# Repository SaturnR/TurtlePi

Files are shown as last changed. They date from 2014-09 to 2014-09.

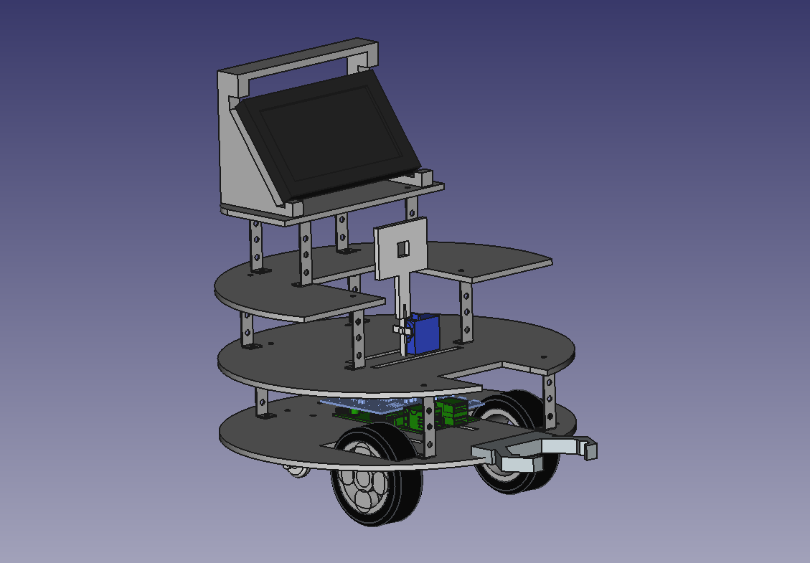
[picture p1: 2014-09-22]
Design/Screenshot from 2014-05-14 19:03:23.png

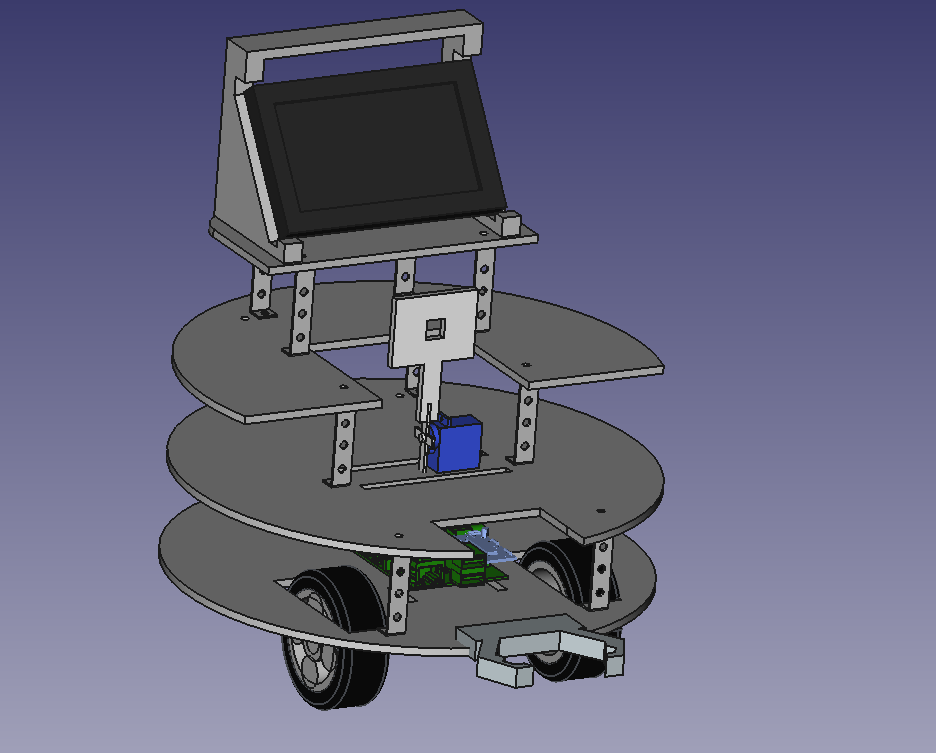
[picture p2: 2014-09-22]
Design/Screenshot from 2014-05-14 19:05:55.png

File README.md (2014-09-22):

TurtlePi
========

Programming and Electronics Learning Robotics kit, for students. 
 
TurtlePi is designed as a learning and research­experimenting robotics kit. 
It can be used for students from 12 year old to universities and colleges. 
kit is entirely modular, wide variety of sensors can be connected easily as a modules and 
actuators presented as a modules too. Robot contains two main board one is arduino 
compatible control board and another is raspberry pi computer, arduino control board is 
designed as shield for Raspberry Pi.  

Arduino board can be used as standalone control board, without Raspberry Pi computer and can 
perform low level tasks such as path planning, obstacle avoidance, line following, remote control. 
In addition with Raspberry Pi computer, robot gets much more complex functionality such as: 
object/face recognition, speech synthesis, Speech Recognition, dynamic programming and etc. 

robotics kit can be controlled and programmed wirelessly, 
In final design, robotics kit can be programmed with wide variety programming languages 
(python, javascript, c, c++, perl, c#) and visual languages like Google Blockly and Scratch.

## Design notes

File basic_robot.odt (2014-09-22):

1. რობოტი გათვლილია ფართო ასაკობრივი ჯგუფებისთვის, დაწყებული III კლასის მოსწავლეებიდან სტუდენტებით დამთავრებული.
2. პროექტი შესრულებულია მთლიანათ მოდულური პრინციპით, მოდულების სახით არის წარმოდგენილი როგორც მართვის ელემენტები ასევე გადამწოდები და შემსრულებელი მექანიზმები.
3. რობოტი წაროდგენილი იქნება ორი სახით, სრული და საბაზისო კომპლექტაციით.
4. სრული კომპლექტაციით შეიცავს ორ მათვის მოდულს, პირველი ეს არის Raspberry pi კომპიუტერი, ხოლო მეორე Arduino, რომელიც თავის მხრივ წარმოადგენს შილდს Raspberry pi-სთვის.
  სრული კომპლექტაციის პირობებში Raspberry pi წარმოადგენს რობოტის მმართველ მოდულს (ბრძანებების მიღება, ვიდეო გამოსახულების დამუშავება, …. ) , ხოლო არდუინო შილდს მხოლოდ პერიფერიული ამოცანების შესრულება აკისრია, როგორიცაა: სერვო ძრავების მართვა , გადამწოდებიდან ციფრული თუ ანალოგური სახის ინფორმაციის მიღება.
5. საბაზისო კომპლექტაციით, რობოტის მართვის მოდულს წარმოადგენს მხოლოდ Arduino მოდული. ხოლო Raspberry pi, RPi კამერა მოდული და მონიტორი არ შედის კომპლექტაციაში. ყველა დანარჩენი გადამწოდები და შემსრულებელი მექანიზმები გათვალისწინებულია კომპლექტაციაში.
6. რობოტის პროგრამირების პროცესი ასევე მნიშვენელოვნათ გამარტივებულია, ნებისმიერი კომპლექტაციის პირობებში პროგრამირების პროცესი არის დისტანციური და არ საჭიროებს სადენის ფიზიკურათ შეერთებას.
7. რობოტის პროგრამირების გარემო მრავალფეროვანია. რობოტის პროგრამირება შესაძლებელია რამოდენიმე პოპულარული პროგრამირების ენით (c, c++, java, perl, javascript, python, c#) და ამასთავე პროგრამირება შესაძლებელი იქნება ვიზუალური პროგრამირების ენითაც.
  შესაძლებლობები
  1. ობიქტების ამოცნობა
  2. გადაადგილება გასაზღვრული კოორდინატების მითითებით.
  3. ობიექტის აღება გადატანა
  4. ხაზის მიყოლა

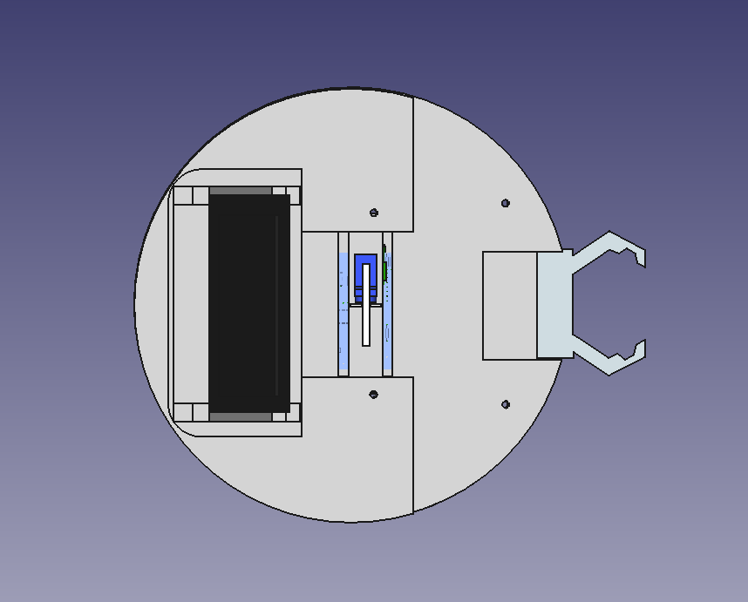
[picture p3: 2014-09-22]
Design/Screenshot from 2014-05-14 19:04:03.png

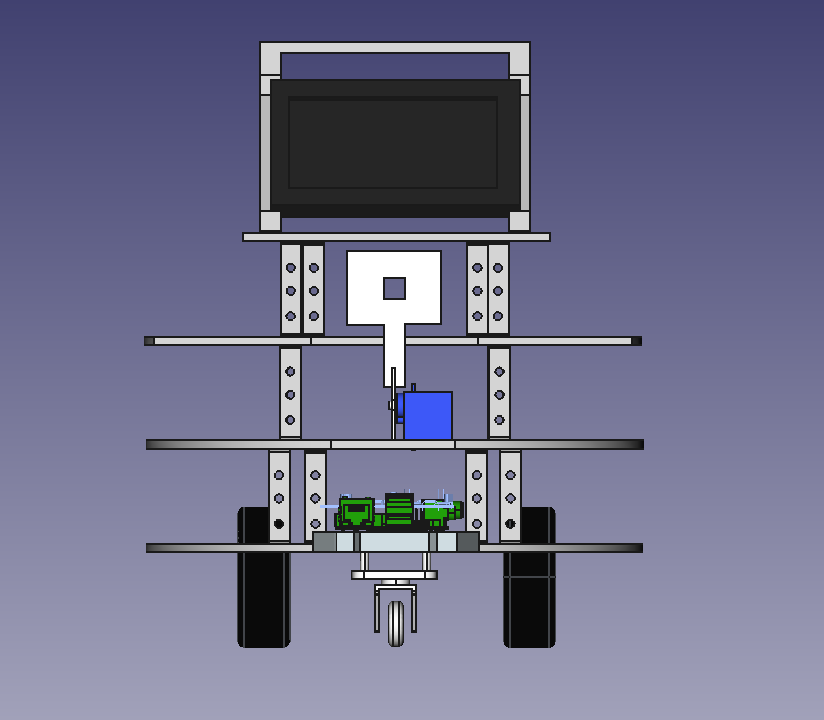
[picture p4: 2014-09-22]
Design/Screenshot from 2014-05-14 19:04:27.png

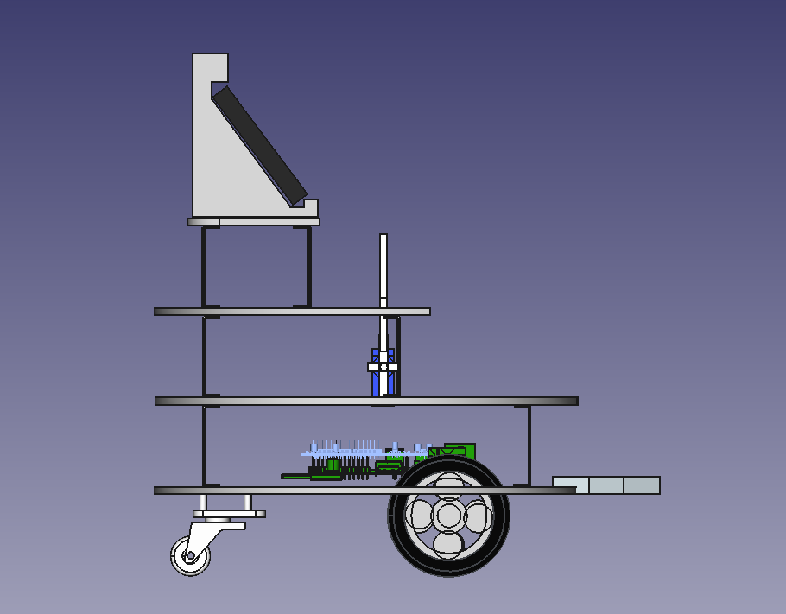
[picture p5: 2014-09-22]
Design/Screenshot from 2014-05-14 19:03:52.png

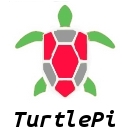
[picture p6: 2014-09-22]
TurtlePi.jpg

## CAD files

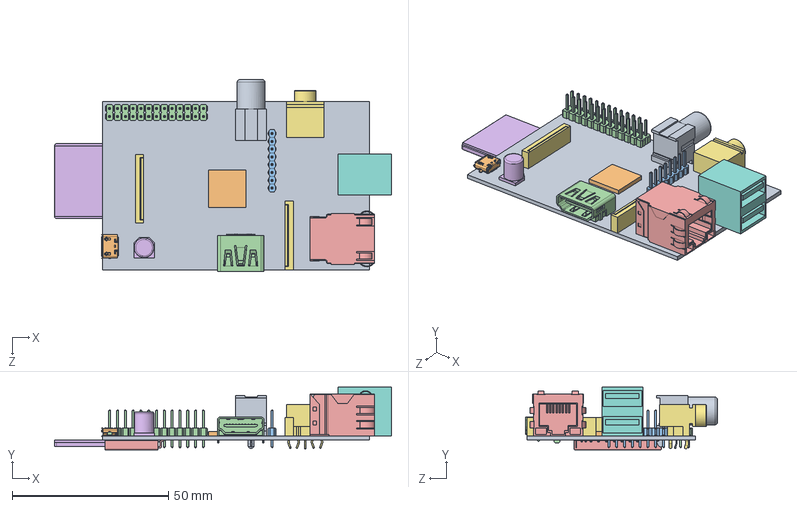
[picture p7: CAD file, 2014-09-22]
Robot_cad_01/RaspBerry.SLDASM
108.0 x 20.1 x 61.5 mm
PCB
micro usb
micro usb02
HDMI.ipt
RJ45.ipt
SD Card
User Library-PJS_05_LB_H
User Library-KUSBLX-AS2N-B Dual USB
User Library-161-0097-kobiconn
Arm11
HDR1x1 x 8
HDR2x2 x 12
User Library-SDC-W25PB-09
converter
dsi x 2

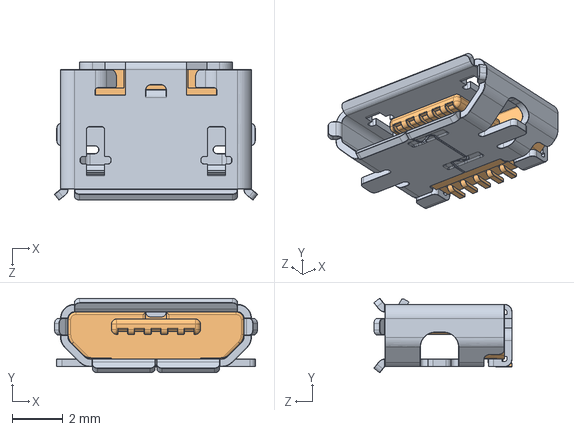
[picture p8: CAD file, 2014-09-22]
Robot_cad/micro USB.SLDASM
7.97 x 2.92 x 5.43 mm
micro usb
micro usb02

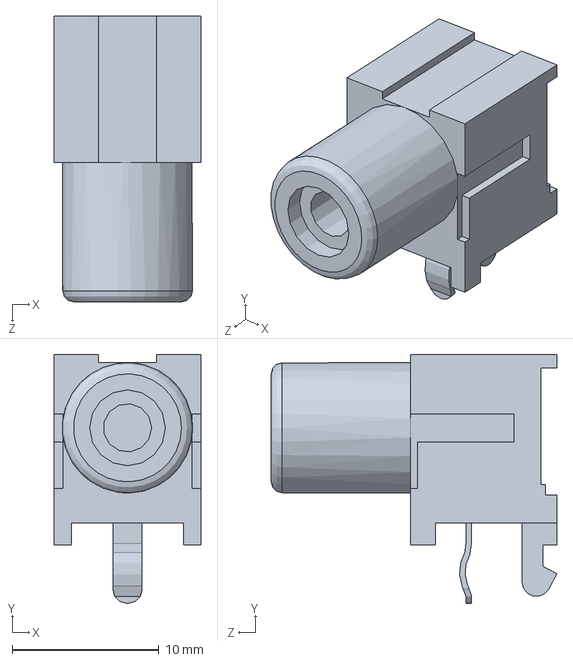
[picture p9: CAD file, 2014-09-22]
Robot_cad/User Library-161-0097-kobiconn.SLDPRT
10.0 x 17.0 x 19.5 mm

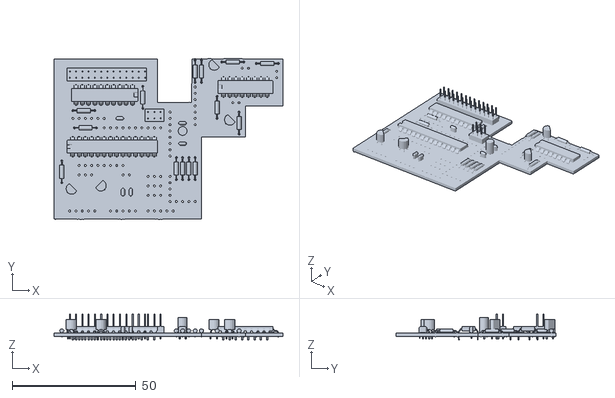
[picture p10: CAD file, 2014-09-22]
Robot_cad_01/rpi_arduino_robot/rpi_arduino_robot.stl
92.7 x 65.2 x 10.4

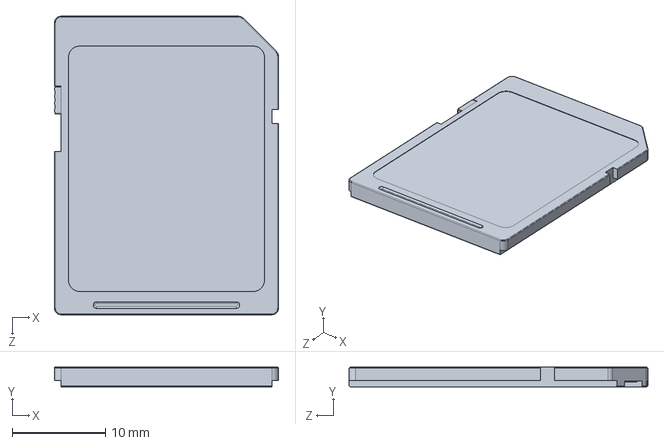
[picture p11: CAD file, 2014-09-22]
Robot_cad/SD Card.SLDPRT
24.0 x 2.10 x 32.0 mm

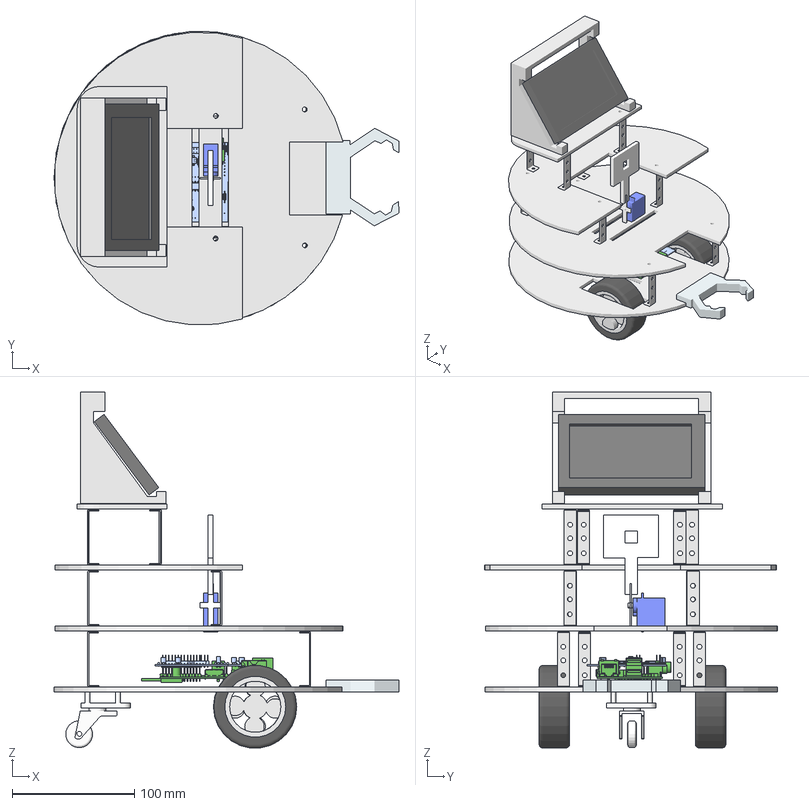
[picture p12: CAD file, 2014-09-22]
Robot_cad_01/robot.fcstd
282.7 x 240.5 x 291.6 mm
back_wheel
gripper
display
camera_Pad
RaspBerry
RaspBerry002
RaspBerry004
RaspBerry006
RaspBerry008
RaspBerry010
RaspBerry012
RaspBerry014
RaspBerry016
RaspBerry018
RaspBerry020
RaspBerry022
RaspBerry024
RaspBerry026
RaspBerry028
RaspBerry030
RaspBerry032
RaspBerry034
RaspBerry036
RaspBerry038
RaspBerry040
RaspBerry042
RaspBerry044
RaspBerry046
RaspBerry048
RaspBerry050
RaspBerry052
RaspBerry005
RaspBerry009
RaspBerry013
RaspBerry017
RaspBerry021
RaspBerry025
RaspBerry029
RaspBerry033
RaspBerry037
RaspBerry041
RaspBerry045
RaspBerry049
RaspBerry003
RaspBerry011
RaspBerry019
RaspBerry027
RaspBerry035
RaspBerry043
RaspBerry051
RaspBerry007
RaspBerry023
RaspBerry039
RaspBerry015
RaspBerry047
RaspBerry031
RaspBerry001
rpi_arduino_robot

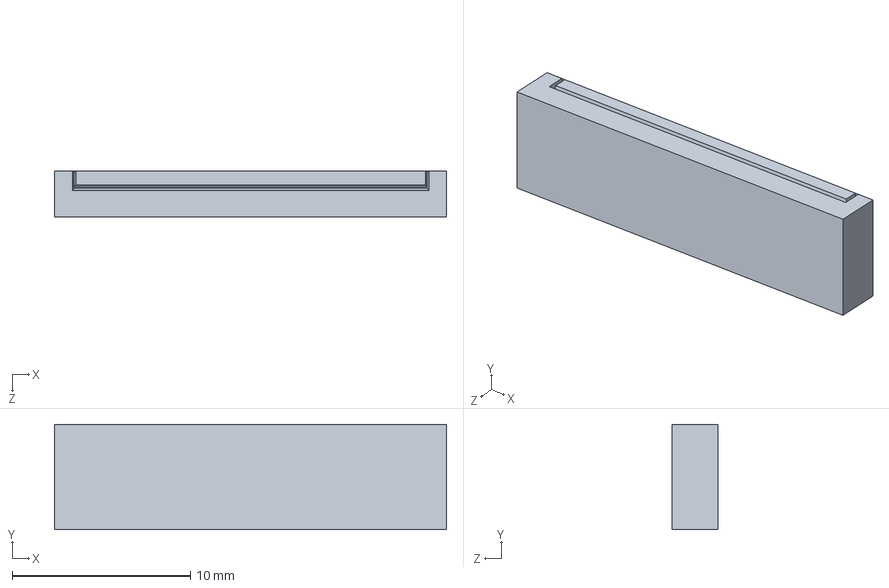
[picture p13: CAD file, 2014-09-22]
Robot_cad/dsi.SLDPRT
22.0 x 5.90 x 2.60 mm

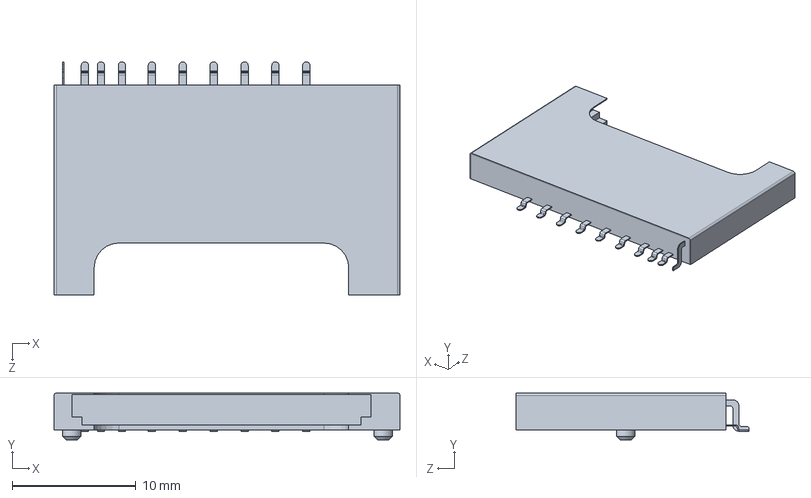
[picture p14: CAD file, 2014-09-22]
Robot_cad_01/User Library-SDC-W25PB-09.SLDPRT
28.0 x 3.80 x 18.9 mm

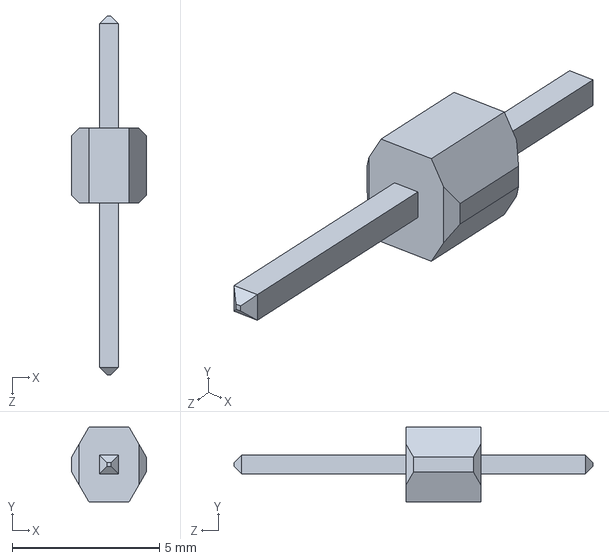
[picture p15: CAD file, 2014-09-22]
Robot_cad/HDR1x1.SLDPRT
2.54 x 2.54 x 12.2 mm

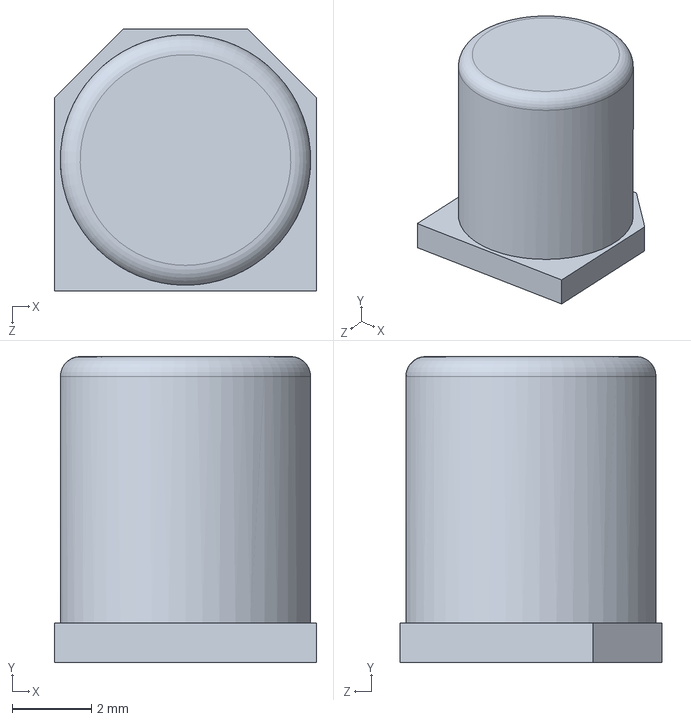
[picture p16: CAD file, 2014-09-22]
Robot_cad/converter.SLDPRT
6.60 x 7.70 x 6.60 mm

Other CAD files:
Robot_cad/rpi_arduino_robot/freecad_ardu.fcstd
Robot_cad_01/rpi_arduino_robot/freecad_ardu.fcstd
Robot_cad_01/robot_part2.fcstd
Robot_cad/Arm11.SLDPRT
Robot_cad/HDMI.ipt.SLDPRT
Robot_cad/HDR2x2.SLDPRT
Robot_cad/PCB.SLDPRT
Robot_cad/RJ45.ipt.SLDPRT
Robot_cad/User Library-KUSBLX-AS2N-B Dual USB.SLDPRT
Robot_cad/User Library-PJS_05_LB_H.SLDPRT
Robot_cad/micro usb.SLDPRT
Robot_cad/micro usb02.SLDPRT
Robot_cad/robot.fcstd
Robot_cad/robot_part2.fcstd
Robot_cad/rpi_arduino_robot/rpi_arduino_robot.ply
Robot_cad_01/Arm11.SLDPRT
Robot_cad_01/HDMI.ipt.SLDPRT
Robot_cad_01/HDR2x2.SLDPRT
Robot_cad_01/PCB.SLDPRT
Robot_cad_01/RJ45.ipt.SLDPRT
Robot_cad_01/User Library-KUSBLX-AS2N-B Dual USB.SLDPRT
Robot_cad_01/User Library-PJS_05_LB_H.SLDPRT
Robot_cad_01/micro usb.SLDPRT
Robot_cad_01/micro usb02.SLDPRT
Robot_cad_01/rpi_arduino_robot/rpi_arduino_robot.ply

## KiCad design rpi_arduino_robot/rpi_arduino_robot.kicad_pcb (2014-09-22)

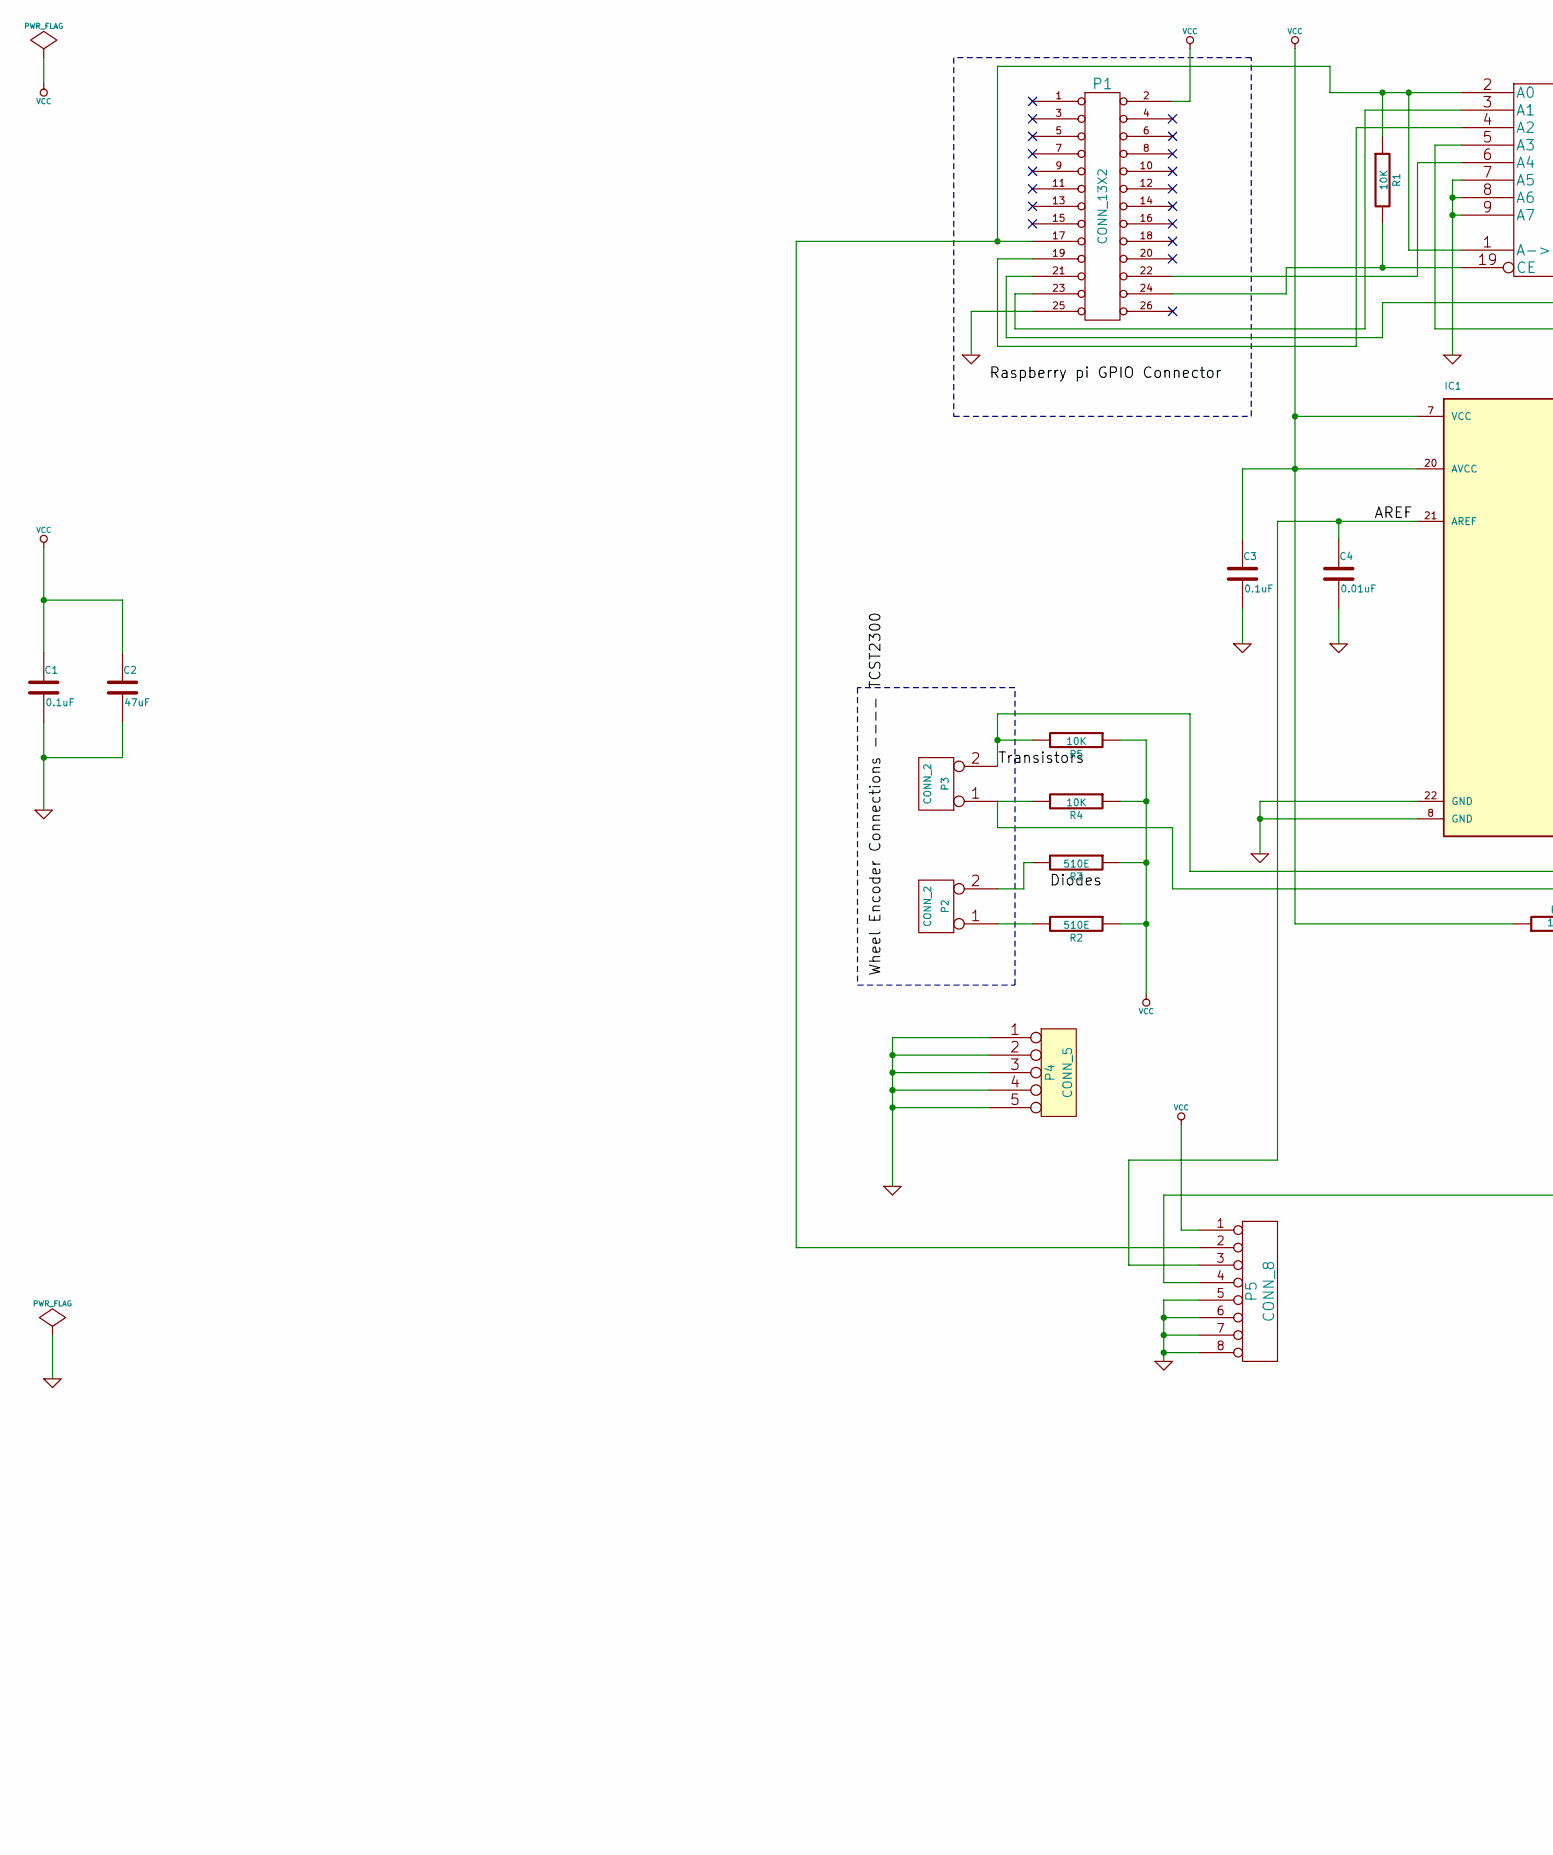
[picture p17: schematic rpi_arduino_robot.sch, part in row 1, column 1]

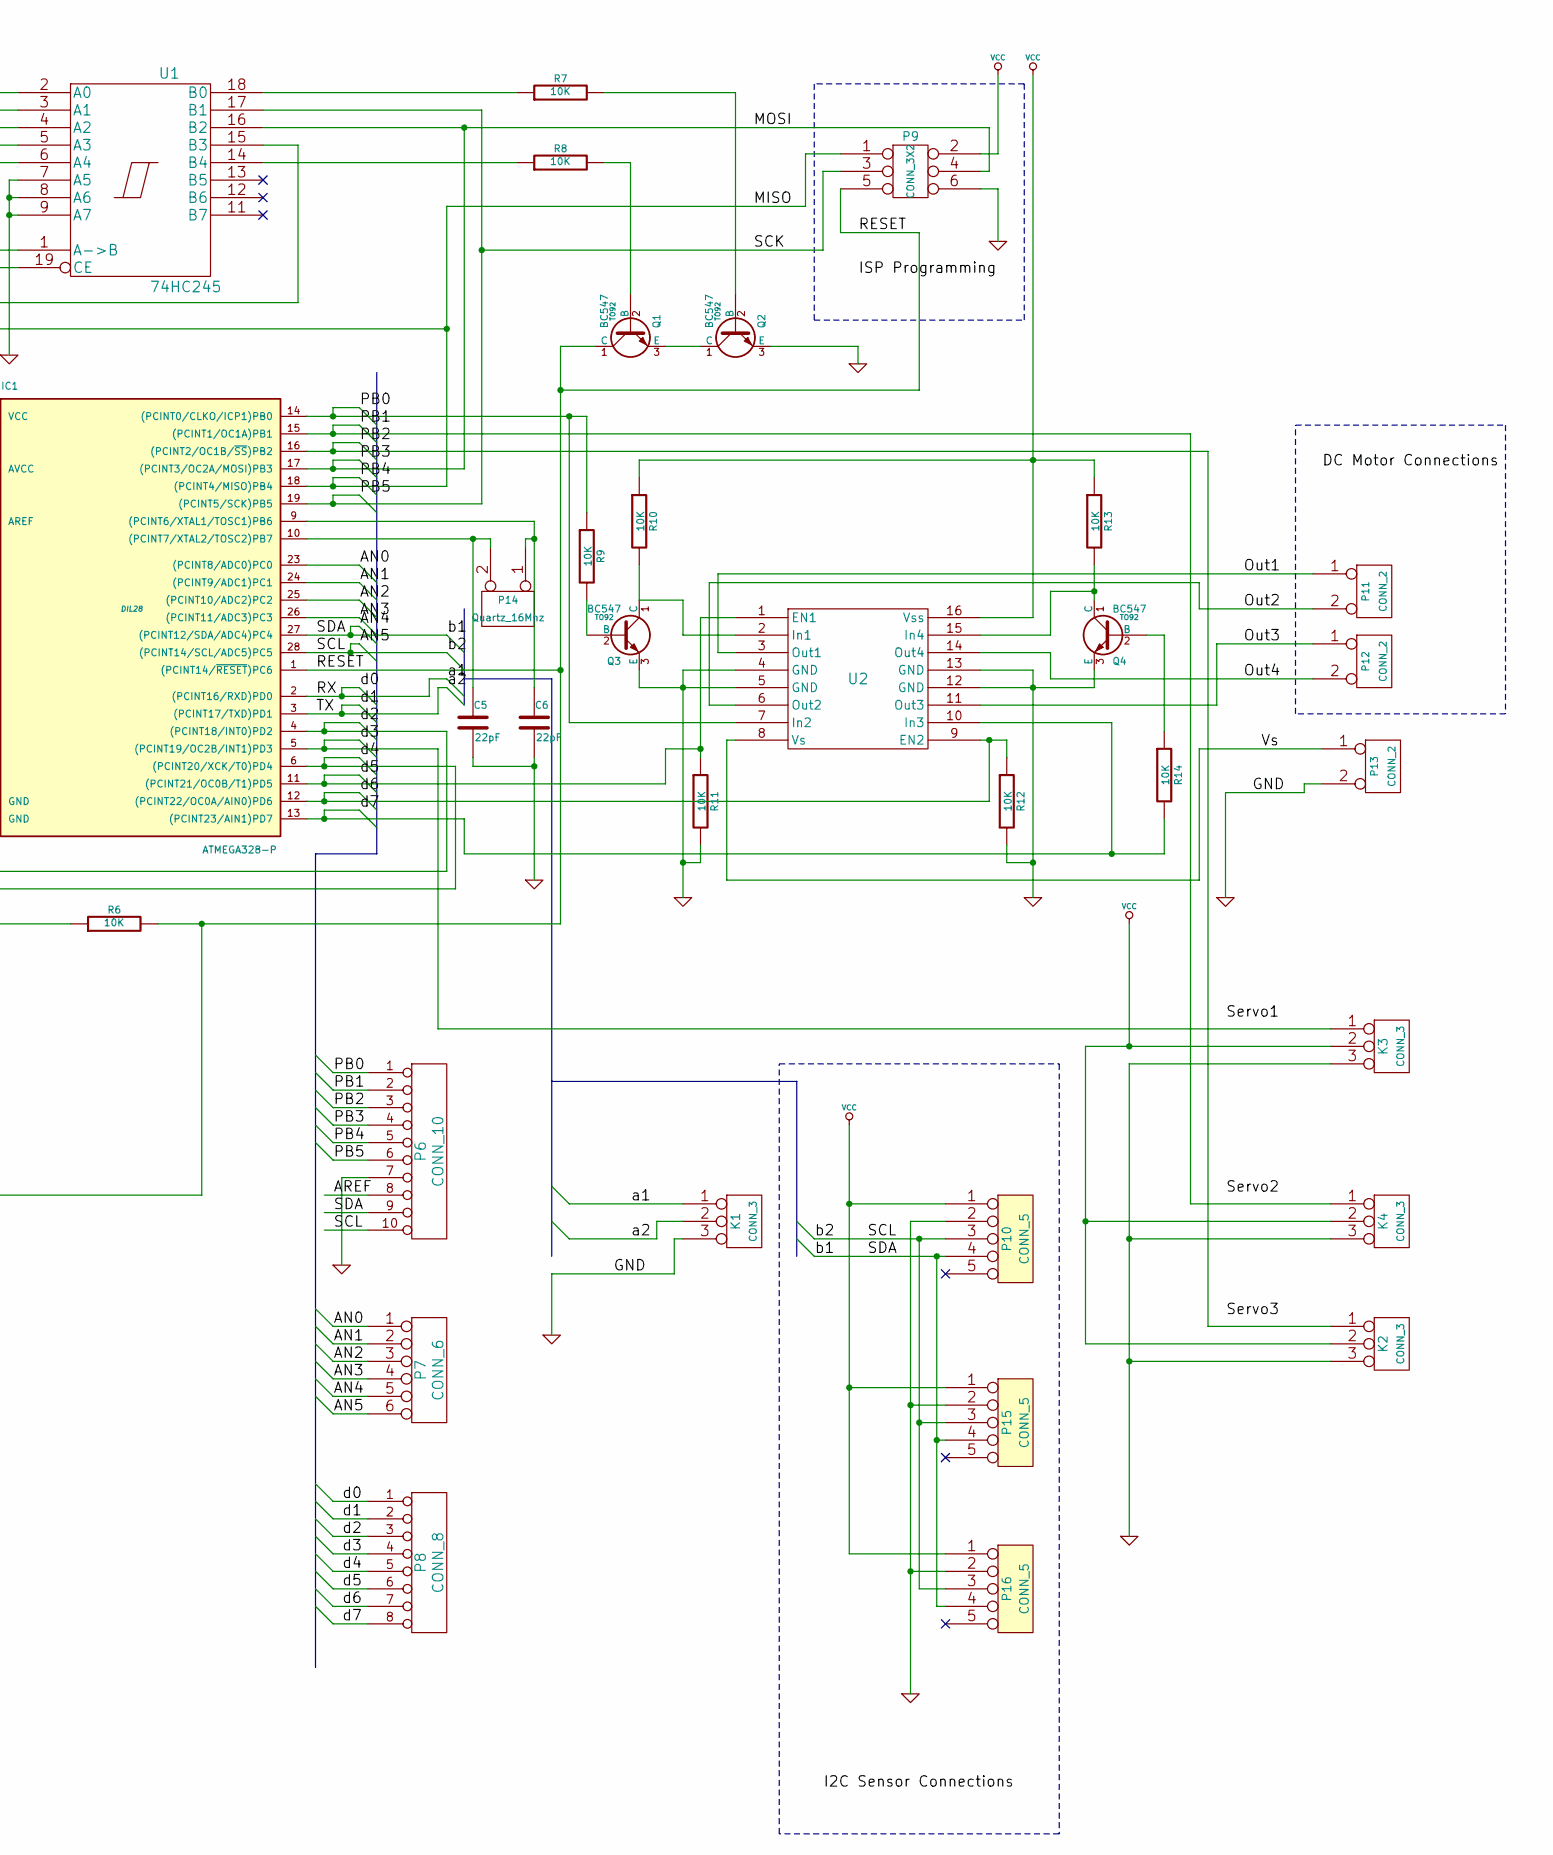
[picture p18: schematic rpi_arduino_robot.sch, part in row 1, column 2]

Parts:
C1, C3: 0.1uF
C2: 47uF
C4: 0.01uF
C5, C6: 22pF
IC1: ATMEGA328-P; DIL28
K1, K2, K3, K4: CONN_3
P1: CONN_13X2
P2, P3, P11, P12, P13: CONN_2
P4, P10, P15, P16: CONN_5
P5, P8: CONN_8
P6: CONN_10
P7: CONN_6
P9: CONN_3X2
P14: Quartz_16Mhz
Q1, Q2, Q3, Q4: BC547; TO92
R1, R4, R5, R6, R7, R8, R9, R10, R11, R12, R13, R14: 10K
R2, R3: 510E
U1: 74HC245
U2: L293D

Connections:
/AN0: IC1.23 ((PCINT8/ADC0)PC0), P7.1
/AN1: IC1.24 ((PCINT9/ADC1)PC1), P7.2
/AN2: IC1.25 ((PCINT10/ADC2)PC2), P7.3
/AN3: IC1.26 ((PCINT11/ADC3)PC3), P7.4
/AN4: IC1.27 ((PCINT12/SDA/ADC4)PC4), P6.9, P7.5, P10.4, P15.4, P16.4
/AN5: IC1.28 ((PCINT14/SCL/ADC5)PC5), P6.10, P7.6, P10.3, P15.3, P16.3
/AREF: C4.1, IC1.21 (AREF), P5.3, P6.8
/MISO: IC1.18 ((PCINT4/MISO)PB4), P6.5, P9.1, U1.5 (A3)
/MOSI: IC1.17 ((PCINT3/OC2A/MOSI)PB3), P6.4, P9.4, U1.16 (B2)
/Out1: P11.1, U2.3 (Out1)
/Out2: P11.2 (PM), U2.6 (Out2)
/Out3: P12.1, U2.11 (Out3)
/Out4: P12.2 (PM), U2.14 (Out4)
/PB0: IC1.14 ((PCINT0/CLKO/ICP1)PB0), P6.1, R9.1, U2.7 (In2)
/PB1: IC1.15 ((PCINT1/OC1A)PB1), K4.1, P6.2
/PB2: IC1.16 ((PCINT2/OC1B/~SS~)PB2), K2.1, P6.3
/PB5: IC1.19 ((PCINT5/SCK)PB5), P6.6, P9.3, U1.17 (B1)
/RESET: IC1.1 ((PCINT14/~RESET~)PC6), P5.4, P9.5, Q1.1 (C), R6.2
/RX: IC1.2 ((PCINT16/RXD)PD0), K1.1, P8.1
/TX: IC1.3 ((PCINT17/TXD)PD1), K1.2 (PM), P8.2
/Vs: P13.1, U2.8 (Vs)
/d2: IC1.4 ((PCINT18/INT0)PD2), P3.2 (PM), P8.3, R5.2
/d3: IC1.5 ((PCINT19/OC2B/INT1)PD3), K3.1, P8.4
/d4: IC1.6 ((PCINT20/XCK/T0)PD4), P3.1, P8.5, R4.2
/d5: IC1.11 ((PCINT21/OC0B/T1)PD5), P8.6, R11.1, U2.1 (EN1)
/d6: IC1.12 ((PCINT22/OC0A/AIN0)PD6), P8.7, R12.1, U2.9 (EN2)
/d7: IC1.13 ((PCINT23/AIN1)PD7), P8.8, R14.2, U2.10 (In3)
GND: C1.2, C2.2, C3.2, C4.2, C5.2, C6.2, IC1.8 (GND), IC1.22 (GND), K1.3, K2.3, K3.3, K4.3, P1.25 (P24), P4.1, P4.2, P4.3, P4.4, P4.5, P5.5, P5.6, P5.7, P5.8, P6.7, P9.6, P10.2, P13.2 (PM), P15.2, P16.2, Q2.3 (E), Q3.3 (E), Q4.3 (E), R11.2, R12.2, U1.7 (A5), U1.8 (A6), U1.9 (A7), U1.10 (GND), U2.4 (GND), U2.5 (GND), U2.12 (GND), U2.13 (GND)
unnamed: P1.17, P5.2, R1.1, U1.1 (A->B), U1.2 (A0)
unnamed: P2.2 (PM), R3.2
unnamed: P2.1, R2.2
unnamed: P1.23, U1.3 (A1)
unnamed: P1.19, U1.4 (A2)
unnamed: P1.21, U1.15 (B3)
unnamed: P1.24 (P20), R1.2, U1.19 (CE)
unnamed: P1.22, U1.6 (A4)
unnamed: C5.1, IC1.10 ((PCINT7/XTAL2/TOSC2)PB7), P14.2 (PM)
unnamed: Q2.2 (B), R7.2
unnamed: Q1.2 (B), R8.2
unnamed: Q3.2 (B), R9.2
unnamed: R8.1, U1.14 (B4)
unnamed: R7.1, U1.18 (B0)
unnamed: Q3.1 (C), R10.2, U2.2 (In1)
unnamed: Q4.1 (C), R13.2, U2.15 (In4)
unnamed: Q1.3 (E), Q2.1 (C)
unnamed: Q4.2 (B), R14.1
unnamed: C6.1, IC1.9 ((PCINT6/XTAL1/TOSC1)PB6), P14.1
VCC: C1.1, C2.1, C3.1, IC1.7 (VCC), IC1.20 (AVCC), K2.2 (PM), K3.2 (PM), K4.2 (PM), P1.2, P5.1, P9.2, P10.1, P15.1, P16.1, R2.1, R3.1, R4.1, R5.1, R6.1, R10.1, R13.1, U1.20 (VCC), U2.16 (Vss)

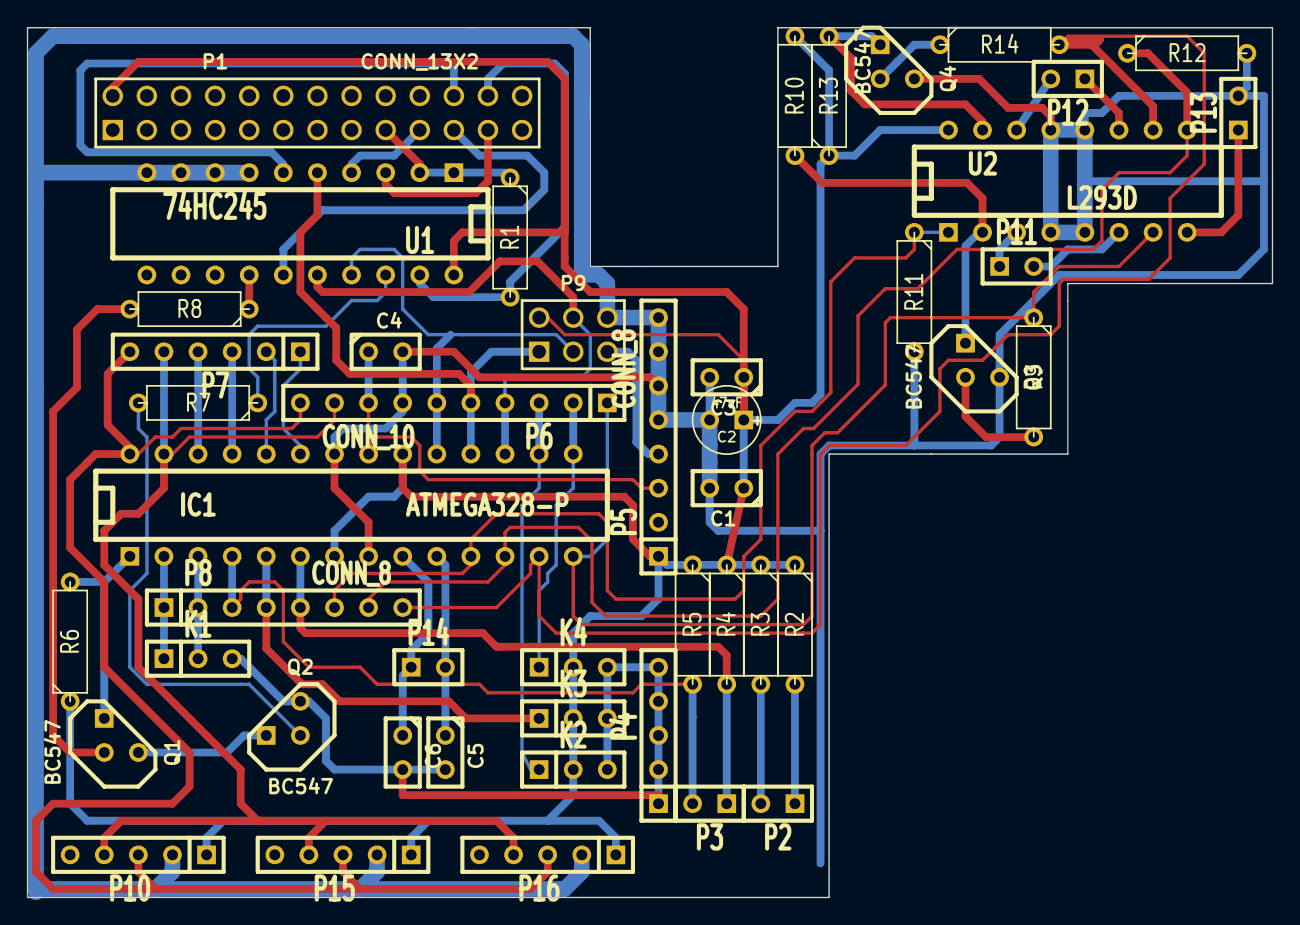
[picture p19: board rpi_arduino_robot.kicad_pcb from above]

Board: 2 copper layers, 92.7 x 64.8 mm, 47 parts (0 on the bottom side), 48 nets.

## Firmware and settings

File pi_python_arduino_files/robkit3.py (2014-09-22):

import spidev
import time
import RPi.GPIO as GPIO

from array import array
import socket
import time
import sys
import simcv
import os

#from Tkinter import Tk
#from tkSimpleDialog import askstring

# --------------- tcp client configuration -------------
#root = Tk()
#root.withdraw()

PORT = 42001
HOST = "192.168.43.64" #askstring('Scratch Connector', 'IP:')
#if not HOST:
#    sys.exit()

print("Connecting...")
scratchSock = socket.socket(socket.AF_INET, socket.SOCK_STREAM)
scratchSock.connect((HOST, PORT))
print("Connected!")

def sendScratchCommand(cmd):
    n = len(cmd)
    a = array('c')
    a.append(chr((n >> 24) & 0xFF))
    a.append(chr((n >> 16) & 0xFF))
    a.append(chr((n >>  8) & 0xFF))
    a.append(chr(n & 0xFF))
    scratchSock.send(a.tostring() + cmd)

def sendValue(name, value):
        """send a 'sensor-update'"""
        bcast_str = 'sensor-update "{name:s}" {value:s}'.format( name=name, value=value)
#        if logger.isEnabledFor(logging.INFO):logger.info('ScratchSender, send value: %s' , bcast_str)
        
        scratchSock.send(bcast_str)

# ---------------------------------------------------

GPIO.setwarnings(False)
GPIO.setmode(GPIO.BCM)
GPIO.setup(25, GPIO.OUT)
GPIO.output(25, GPIO.LOW)

spi=spidev.SpiDev()

spi.open(0,0)

def clear():

     GPIO.output(25, GPIO.HIGH)
     spi.writebytes([0])
     time.sleep(0.05)
     GPIO.output(25, GPIO.LOW)
     time.sleep(0.1)

'''
    b=[1,12,0,0,125,111]
    a=spi.xfer([1,12,0,0,125,111])
    time.sleep(0.01)
    while((a[1:]!=b[0:5]) or (a[0]!=0)):
        a=spi.xfer([1,12,0,0,125,111])
        if(a[0]==111): 
            GPIO.output(25, GPIO.HIGH)
        else:
            GPIO.output(25, GPIO.LOW)
    time.sleep(0.01)
    print(a)
'''

def readAngle():
    return 0


def moution(ang,m):
    return [0,0]


def left(angle):
    an1=angle/256
    an0=angle%256
    b=[1,1,an1,an0,135,111]
    a=spi.xfer([1,1,an1,an0,135,111])
    time.sleep(0.01)
    while((a[1:]!=b[0:5]) or (a[0]!=0)):
        a=spi.xfer([1,1,an1,an0,135,111])
        if(a[0]==111): 
            GPIO.output(25, GPIO.HIGH)
        else:
            GPIO.output(25, GPIO.LOW)
    print(a)

def right(angle):
    an1=angle/256
    an0=angle%256
    b=[1,2,an1,an0,135,111]
    a=spi.xfer([1,2,an1,an0,135,111])
    print(a)

'''    time.sleep(0.01)
    while((a[1:]!=b[0:5]) or (a[0]!=0)):
        a=spi.xfer([1,2,an1,an0,125,111])
        if(a[0]==111): 
            GPIO.output(25, GPIO.HIGH)
        else:
            GPIO.output(25, GPIO.LOW)
'''


def goStraight(dist):
    dist_1=dist/256
    dist_0=dist%256
    b=[6,dist_1,dist_0,135,1]
    spi.xfer(b)
    #a=spi.xfer([3,dist_1,dist_0,135,1,1,1,1])
    #time.sleep(0.1)
    #f=spi.xfer([191,0,0,0,1,1,1,1])
    #f=spi.readbytes(1)
    #if(f[0]!=3):
    #    clear()
    #    goStraight(dist)    
    #spi.xfer([111])
    print(b)

'''    time.sleep(0.01)
    while((a[1:]!=b[0:5]) or (a[0]!=0)):
        a=spi.xfer([1,3,dist_1,dist_0,125,111])
        if(a[0]==111): 
            GPIO.output(25, GPIO.HIGH)
        else:
            GPIO.output(25, GPIO.LOW)
    print(a)   
''' 

def goBack(dist):
    dist_1=dist/256
    dist_0=dist%256
    b=[8,dist_1,dist_0,135,1]
    spi.xfer(b)
    #time.sleep(0.1)
    #f=spi.xfer([191,0,0,0,1,1,1,1])
    #f=spi.readbytes(1)
    #if(f[0]!=4):
    #    clear()
    #    goBack(dist)
    #spi.xfer([111])
    print(b)

''' time.sleep(0.01)
    while((a[1:]!=b[0:5]) or (a[0]!=0)):
        a=spi.xfer([1,4,dist_1,dist_0,125,111])
        if(a[0]==111): 
            GPIO.output(25, GPIO.HIGH)
        else:
            GPIO.output(25, GPIO.LOW)'''
#    print(a)    


def magPosition(angle):
    pwm=135
    an1=angle/256
    an0=angle%256
    
    b=[16,an1,an0,pwm,1]
    spi.xfer(b)
    print(b)

def clearPosition():
    spi.xfer([22,0,0,0,0])


def stopCompass():
    a=[24,0,0,0,0]
    f=spi.xfer(a)
    #if(f[0]!=8):
    #    clear()
    #    stopCompass()
    #spi.xfer([111])
    print(a)


def gripPosition(angle):
    #clear()
    pwm=120
    an1=angle/256
    an0=angle%256
    a=[10,an1,an0,pwm,1]
    #f=spi.readbytes(1)
    #if(f[0]!=5):
    #    clear()
    #    gripPosition(angle)
    spi.xfer(a)
    print(a)
def camPosition(angle):
    #clear()
    pwm=120
    an1=angle/256
    an0=angle%256
    a=[12,an1,an0,pwm,1]
    #f=spi.readbytes(1)
    spi.xfer(a)
    print(a)


def jointPosition(angle):
    pwm=120
    an1=angle/256
    an0=angle%256
    a=[14,an1,an0,pwm,1]
    #time.sleep(0.5)
    #f=spi.readbytes(1)
    #if(f[0]!=9):
    #clear()
    #    jointPosition(angle)
    spi.xfer(a)
    print(a)


def readCompass():
    spi.xfer([18])
    time.sleep(0.1)
    spi.readbytes(1)
    f=spi.readbytes(1)
    MSB=f[0]
    print(MSB)
    f=spi.readbytes(1)
    spi.readbytes(1)
    LSB=f[0]
    print(LSB)
    r=(MSB<<8)+LSB;
    print(str(r))
    return r


#========================== camera functions =================
'''
cam = None
qr = None
fc = None

def startCamera():
    co=simcv.ObjectRead()
    #global cam
    qr=simcv.QR()
    fc=simcv.Face()
    cam = co.startCamera()

def stopCamera():
    del cam
    del qr
    del fc

def QRxy():
    #global qr
    return qr.getXY(display=False)

def getfaceXY():
    #global fc
    return fc.getXY(display=False)

'''
#========================== client side========================

#--------------------------------------------------------------

qr = simcv.QR(display=False)
camera = qr.startCamera(width=640,height=480) # width=1280,height=960) 
fc = simcv.Face(display=False)
fc.cam = camera

while True:
    #print('start')
    time.sleep(0.01)
    dat=scratchSock.recv(1024)
    if not dat: break
    cmm=dat.split(' "')[1].split("'")
    #print(dat)
    if(len(cmm)>1):
        dist=int(float(cmm[0]))
        com=cmm[1]
        name=cmm[2].split('"')[0]
#        print(com)
        print('distance='+str(dist) +'-and command-'+com)

        if(com=='straight'):
            goStraight(dist)
            print("str")           
            #time.sleep(dist/100)           
        if(com=='back'):
            goBack(dist)
            print("back"+str(dist))           
            #time.sleep(dist/100)
        elif(com=='left'):
            magPosition(int(dist))
            print("left")
            #time.sleep(1)
        elif(com=='right'):
            magPosition(int(dist))
            print("right")
            #time.sleep(1)
        elif(com=='clearposit'):
            clearPosition()
            print('clear mag position')
            time.sleep(0.5)
        elif(com=='reset'):
            clear()
            print("clear")
            time.sleep(0.1)
        elif(com=='stopcompass'):
            stopCompass()
            print("stop comapss")
        elif(com=='readcompass'):
            sendScratchCommand('sensor-update "compass" '+str(readCompass()))
            #readCompass()
            #sendValue("GetComapass",str(readCompass()))
            print("send compass value")
            time.sleep(0.01)
        elif(com=='getqrxy'):
            xy = qr.getXY()
            if(xy): 
                print(xy) #------------------------
                sendScratchCommand('sensor-update "QRx" '+str(xy[0].x))
                sendScratchCommand('sensor-update "QRy" '+str(xy[0].y))
            else:
                sendScratchCommand('sensor-update "QRx" '+str(None))
                sendScratchCommand('sensor-update "QRy" '+str(None))
        elif(com=='getqrdist'):
            qrd=qr.getXY()
            if(qrd): 
                dist = 44800/qrd[0].width()
                print(dist) #----------------------
                sendScratchCommand('sensor-update "QRdist" '+str(dist))
            else:
                sendScratchCommand('sensor-update "QRdist" '+str(None))
        elif(com=='getfacexy'):
            xy=fc.getXY()
            if(xy): 
                print(xy)
                sendScratchCommand('sensor-update "faceX" '+str(xy[0]))
                sendScratchCommand('sensor-update "faceY" '+str(xy[1]))
        elif(com=='saveface'):
            saved=fc.saveFace(name)
            sendScratchCommand('sensor-update "faceSaved" '+str(saved))
            print(saved)
        elif(com=='recognise'):
            keypoints=fc.recognise(name)
            sendScratchCommand('sensor-update "faceRecognition" '+str(keypoints))
            print(keypoints) 
        elif(com=='camposition'):
            camPosition(dist)
            print('camposition')
            time.sleep(0.01)
        elif(com=='gripper'):
            gripPosition(dist)
            print('gripper')
            time.sleep(0.01)
        elif(com=='joint'):
            jointPosition(dist)
            print('joint')
            time.sleep(0.01)
        elif(com=='speak'):
            os.system("espeak -v ka --stdout '"+name+ "' | aplay -D hw:1,0")
            
           
#===============================================================
'''clear()
while(1):
    magPosition(0)
    time.sleep(3)
    magPosition(90)
    time.sleep(3)
    magPosition(180)
    time.sleep(3)
    magPosition(270)
    time.sleep(3)
    magPosition(360)
    time.sleep(3)
    magPosition(270)
    time.sleep(3)
    magPosition(180)
    time.sleep(3)
    magPosition(90)
    time.sleep(3)
    magPosition(0)
#    clear()
'''


'''
#QR read
qr=simcv.QR(display=True)
qr.startCamera() #width=1280,height=960)

while(1):
    xy =qr.getXY()
    if(xy): print(xy)
    time.sleep(1)
'''
'''
#save face
fc=simcv.Face(display=False)
fc.startCamera(width=320,height=240)

while(1):
    xy=fc.getXY()
    if(xy): print(xy)
    time.sleep(1)

'''
''' 
#recognise
fc=simcv.Face(display=False)
fc.startCamera(width=640,height=480)

while(1):
    #keypoints=fc.saveFace("irakli")
    keypoints=fc.recognise('irakli')
    print(keypoints)
    time.sleep(1)
'''

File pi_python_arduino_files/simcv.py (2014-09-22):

#! /usr/bin/env python

import time
import os.path as path
from SimpleCV import Color, Image, np, Camera

class ObjectRead():
    def __init__(self, display=False):
        self.display=display
    
    img=None
    cam=None
    
    def startCamera(self,width=640,height=480):
        self.cam = Camera(0, { "width": width, "height": height })
        return self.cam
    
    def getImage(self):
        self.img=self.cam.getImage()
        return self.img    
    
class QR(ObjectRead):
    
    img=None
    bar=None
    def __init__(self,display=False):
        self.display=display
    
    def getXY(self):
        self.img=self.getImage()
        self.bar=self.img.toGray().findBarcode()
        if(self.display):
            #if(self.bar): self.bar.draw()
            self.img.show()
            
        return self.bar
    
class Face(ObjectRead):
    faces=None
    face=None
    faceImage=None
    DBfaces=None
    
    def __init__(self,display=False):
        self.display=display
        self.quality = 200 #400
        self.minMatch = 0.3 #0.3
        self.mode = "unsaved"
        self.saved = False
        self.minDist = 0.25
            
    def getXY(self):
        self.img = self.getImage() 
        self.faces = self.img.findHaarFeatures("./facetrack-training.xml")
        ret=None
        if(self.faces): 
            self.face=self.faces[-1]
            #if(self.display):self.face.draw()
            ret= (self.face.x, self.face.y)
        if(self.display): self.img.show()
        return ret
    
    def saveFace(self,name):
        self.img = self.getImage() 
        self.faces = self.img.findHaarFeatures("./facetrack-training.xml")
        ret=True
        if(self.faces): 
            self.face=self.faces[-1]
            #if(self.display): self.face.draw()
            self.face.crop().save("./faces/"+name+".jpg")
            ret=True
        else:
            ret=False 
        if(self.display): self.img.show()
        return ret
    
    def getFace(self, name):
        self.faceImage = Image(name)
        return faceImage
    
    def recognise(self,facename='irakli'):
        if(not facename): savedface=self.face
        self.img = self.getImage()
        self.faces = self.img.findHaarFeatures("./facetrack-training.xml") 
        #if(self.display): self.faces.draw()
        rec=None
        if(self.faces):       
            self.face = self.faces[-1]
            template = self.face.crop()
            template.save("./faces/tempface.jpg")
            rec=Image('./faces/'+facename+'.jpg').findKeypointMatch(template,self.quality,self.minDist,self.minMatch)
        if(self.display): self.img.show()
        return rec


'''
qr=QR(display=True)

qr.startCamera(width=320,height=240) #(width=160,height=120)

while(1):
    xy=qr.getXY()
    print(xy)
    time.sleep(1)
'''
'''
f=Face(display=True)    
cam=f.startCamera()

while(1):
    #f.saveFace('111')
    keypoints=f.recognise('irakli',display=True)
    print(keypoints)
    time.sleep(1)
'''
